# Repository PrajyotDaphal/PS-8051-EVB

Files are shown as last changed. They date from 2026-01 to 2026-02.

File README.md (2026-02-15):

# PS-8051-EVB  
**8051 Microcontroller Evaluation Board**

## 📌 Project Overview
PS-8051-EVB is a custom-designed **8051 microcontroller evaluation board** developed for embedded systems learning and prototyping. The board integrates a regulated 5V power supply, USB-to-UART communication using FT232RL, crystal oscillator, reset circuitry, and multiple 2.54 mm IDC connectors for external interfacing.

## ⚙️ Key Features
- 8051 microcontroller (40-pin DIP / ZIF socket compatible)
- Onboard 5V regulated power supply (L7805)
- USB-to-UART interface using FT232RL
- External crystal oscillator circuit
- Reset circuitry for reliable startup
- 2.54 mm IDC headers for I/O expansion
- Mounting holes for enclosure fitting

## 🛠 Tools Used
- KiCad EDA (Schematic & PCB Layout)

## 📐 Design Files
- Complete KiCad schematic and PCB layout
- Manufacturing-ready Gerber files
- Project images and documentation

## 🖼 Schematic
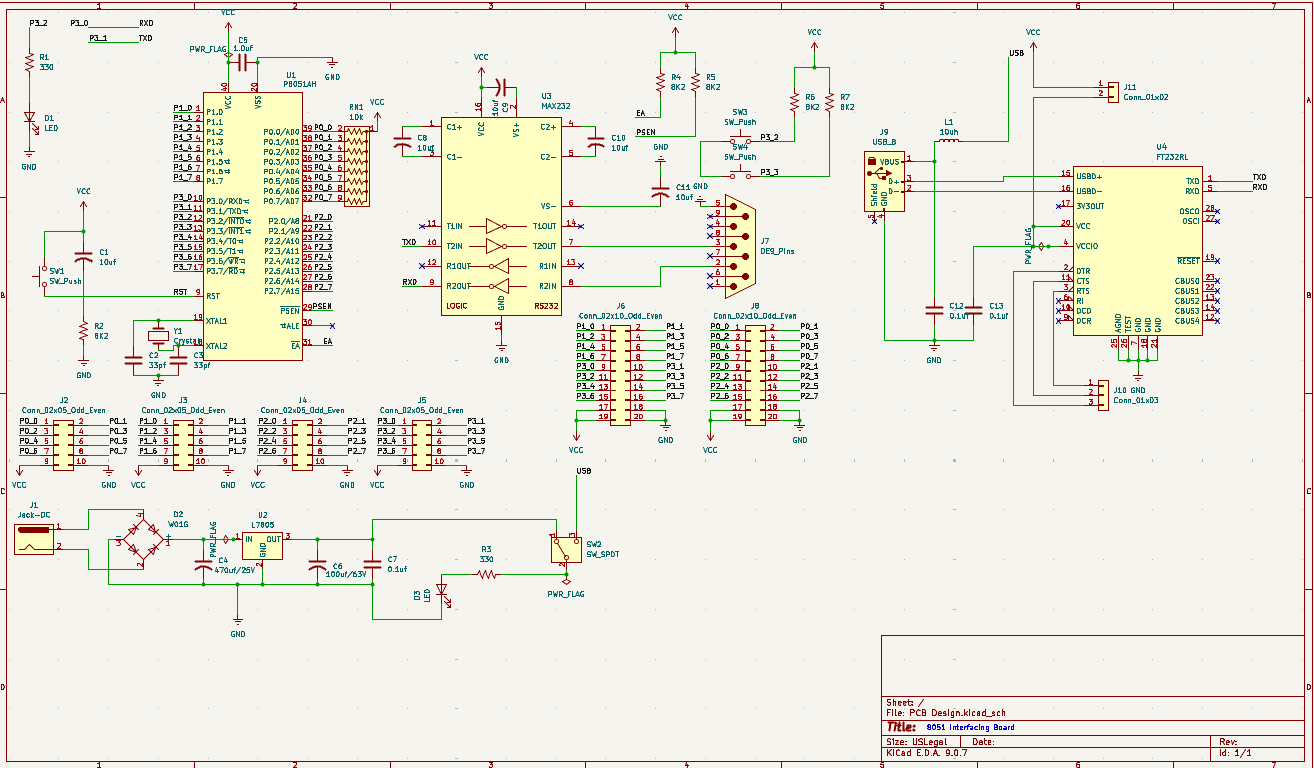
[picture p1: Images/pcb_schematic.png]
Schematic


## 🧩| Full Layout | Upper Copper | Lower Copper |
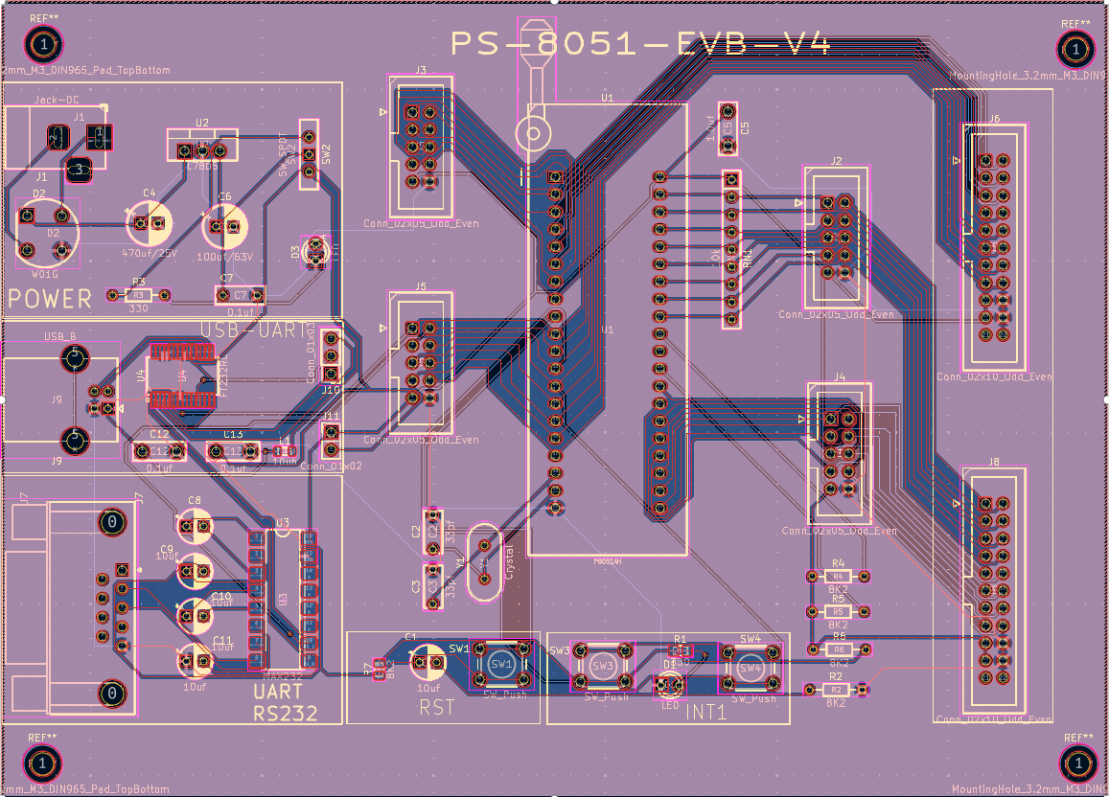
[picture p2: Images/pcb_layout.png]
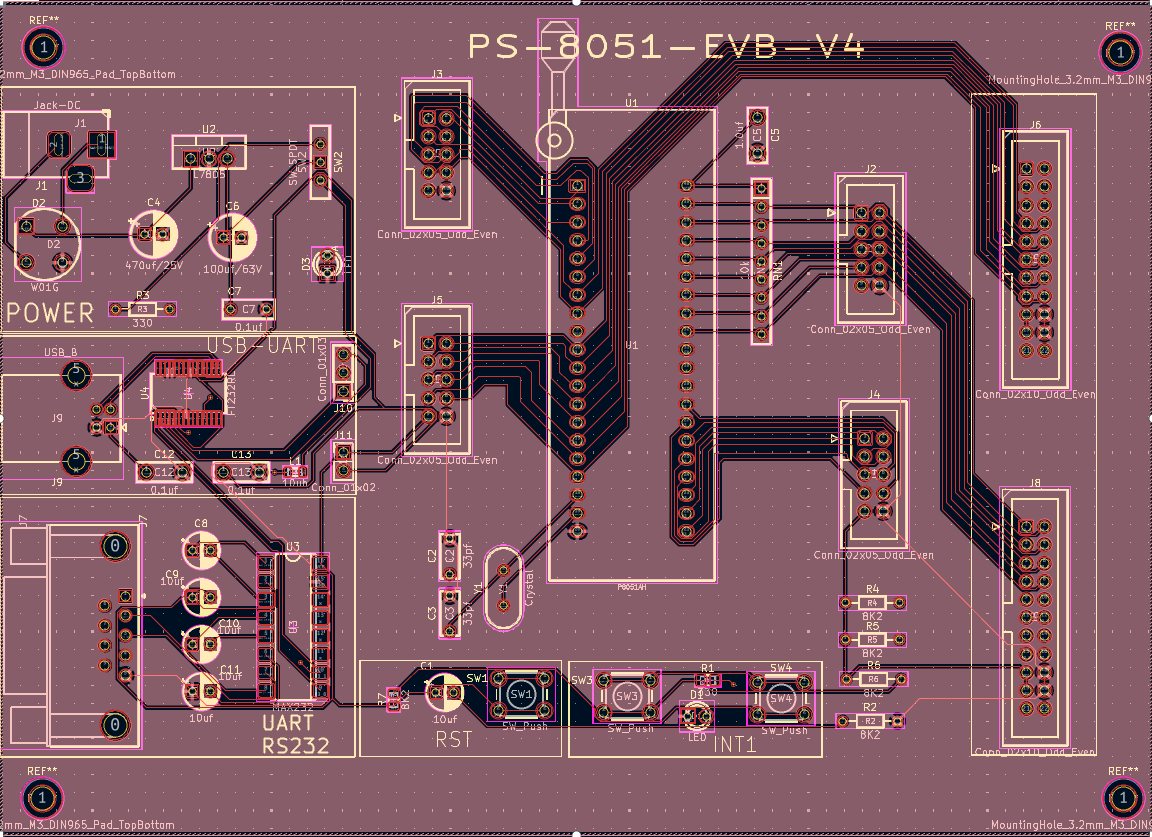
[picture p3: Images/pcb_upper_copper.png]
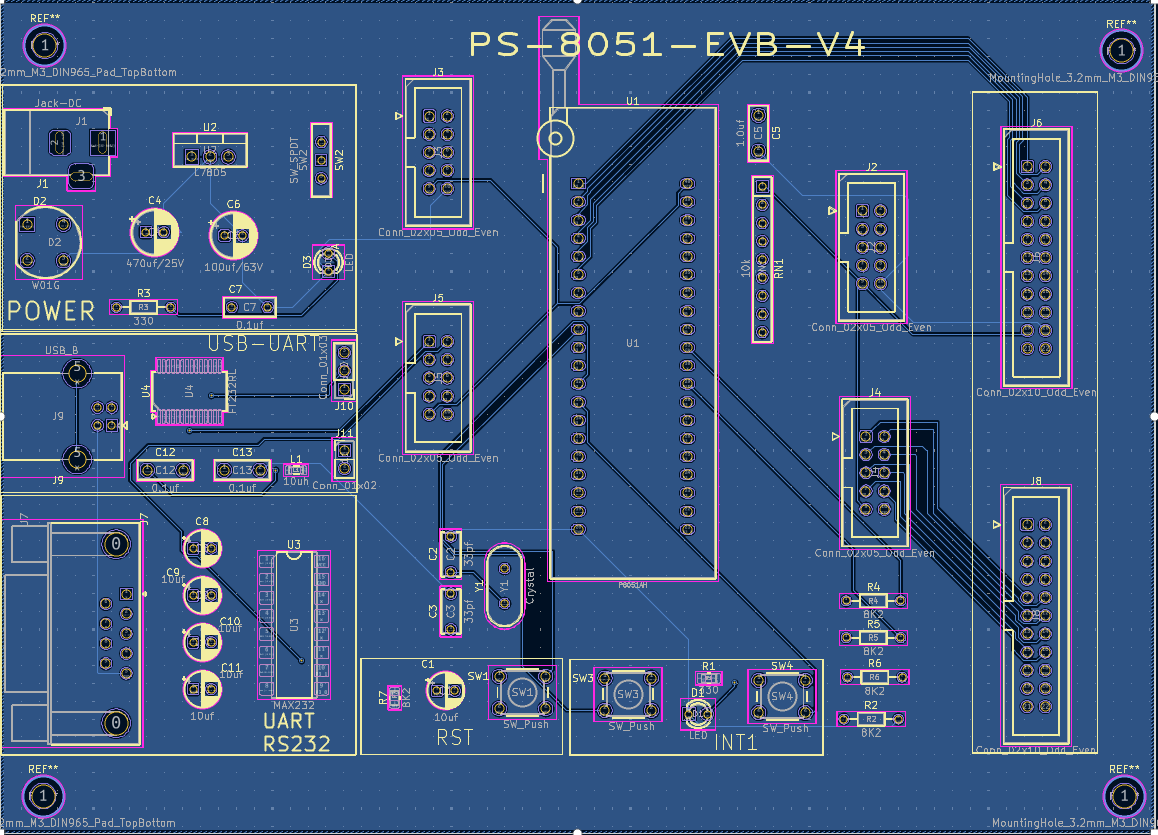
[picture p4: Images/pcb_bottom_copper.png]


## 🔷 PCB 3D View
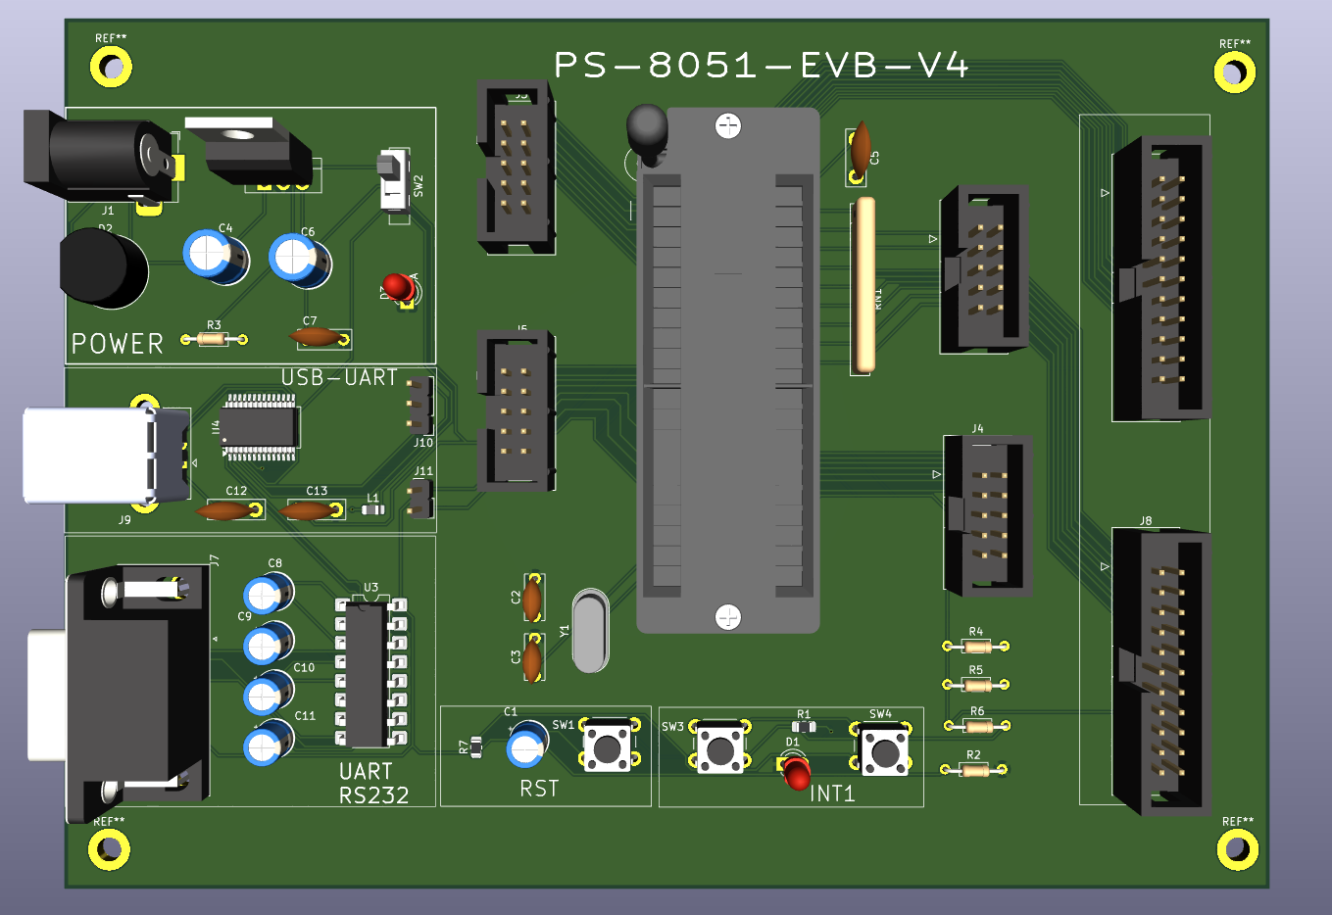
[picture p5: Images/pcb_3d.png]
PCB 3D


## 📂 Repository Structure
PS-8051-EVB/
├─ kicad/
├─ images/
├─ gerber/
├─ bom/
└─ README.md

## 🎯 Applications
- Embedded systems learning
- 8051 microcontroller experiments
- USB-based serial communication projects
- Academic and training use

## 👤 Author
**Prajyot Daphal**  
ENTC Engineering Student

---

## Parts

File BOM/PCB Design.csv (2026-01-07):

Id | Designator | Footprint | Quantity | Designation | Supplier and ref
1 | D3,D1 | LED_D3.0mm | 2 | LED
2 | C8,C9,C11,C10,C1 | CP_Radial_D5.0mm_P2.50mm | 5 | 10uf
3 | RN1 | R_Array_SIP9 | 1 | 10k
4 | U1 | DIP_Socket-40_W11.9mm_W12.7mm_W15.24mm_W17.78mm_W18.5mm_3M_240-1280-00-0602J | 1 | P8051AH
5 | R4,R5,R6,R2 | R_Axial_DIN0204_L3.6mm_D1.6mm_P7.62mm_Horizontal | 4 | 8K2
6 | J6,J8 | IDC-Header_2x10_P2.54mm_Vertical | 2 | Conn_02x10_Odd_Even
7 | SW2 | SW_Slide-03_Wuerth-WS-SLTV_10x2.5x6.4_P2.54mm | 1 | SW_SPDT
8 | J9 | USB_B_Lumberg_2411_02_Horizontal | 1 | USB_B
9 | J2,J4,J3,J5 | IDC-Header_2x05_P2.54mm_Vertical | 4 | Conn_02x05_Odd_Even
10 | Y1 | Crystal_HC49-4H_Vertical | 1 | Crystal
11 | J1 | BarrelJack_Horizontal | 1 | Jack-DC
12 | C12,C13 | C_Disc_D7.5mm_W2.5mm_P5.00mm | 2 | 0.1uf
13 | C3,C2 | C_Disc_D6.0mm_W2.5mm_P5.00mm | 2 | 33pf
14 | C4 | CP_Radial_D8.0mm_P5.00mm | 1 | 470uf/25V
15 | SW4,SW3,SW1 | SW_PUSH_6mm | 3 | SW_Push
16 | L1 | L_0805_2012Metric | 1 | 10uh
17 | J10 | PinHeader_1x03_P2.54mm_Vertical | 1 | Conn_01x03
18 | C6 | CP_Radial_D6.3mm_P2.50mm | 1 | 100uf/63V
19 | R1 | R_0805_2012Metric_Pad1.20x1.40mm_HandSolder | 1 | 330
20 | R3 | R_Axial_DIN0204_L3.6mm_D1.6mm_P7.62mm_Horizontal | 1 | 330
21 | C7 | C_Disc_D7.0mm_W2.5mm_P5.00mm | 1 | 0.1uf
22 | C5 | C_Disc_D7.5mm_W2.5mm_P5.00mm | 1 | 1.0uf
23 | R7 | R_0805_2012Metric | 1 | 8K2
24 | J7 | DSUB-9_Pins_Horizontal_P2.77x2.84mm_EdgePinOffset7.70mm_Housed_MountingHolesOffset9.12mm | 1 | DE9_Pins
25 | D2 | Diode_Bridge_Round_D9.8mm | 1 | W01G
26 | U2 | TO-220-3_Vertical | 1 | L7805
27 | U4 | SSOP-28_5.3x10.2mm_P0.65mm | 1 | FT232RL
28 | J11 | PinHeader_1x02_P2.54mm_Vertical | 1 | Conn_01x02
29 | U3 | SMDIP-16_W7.62mm | 1 | MAX232

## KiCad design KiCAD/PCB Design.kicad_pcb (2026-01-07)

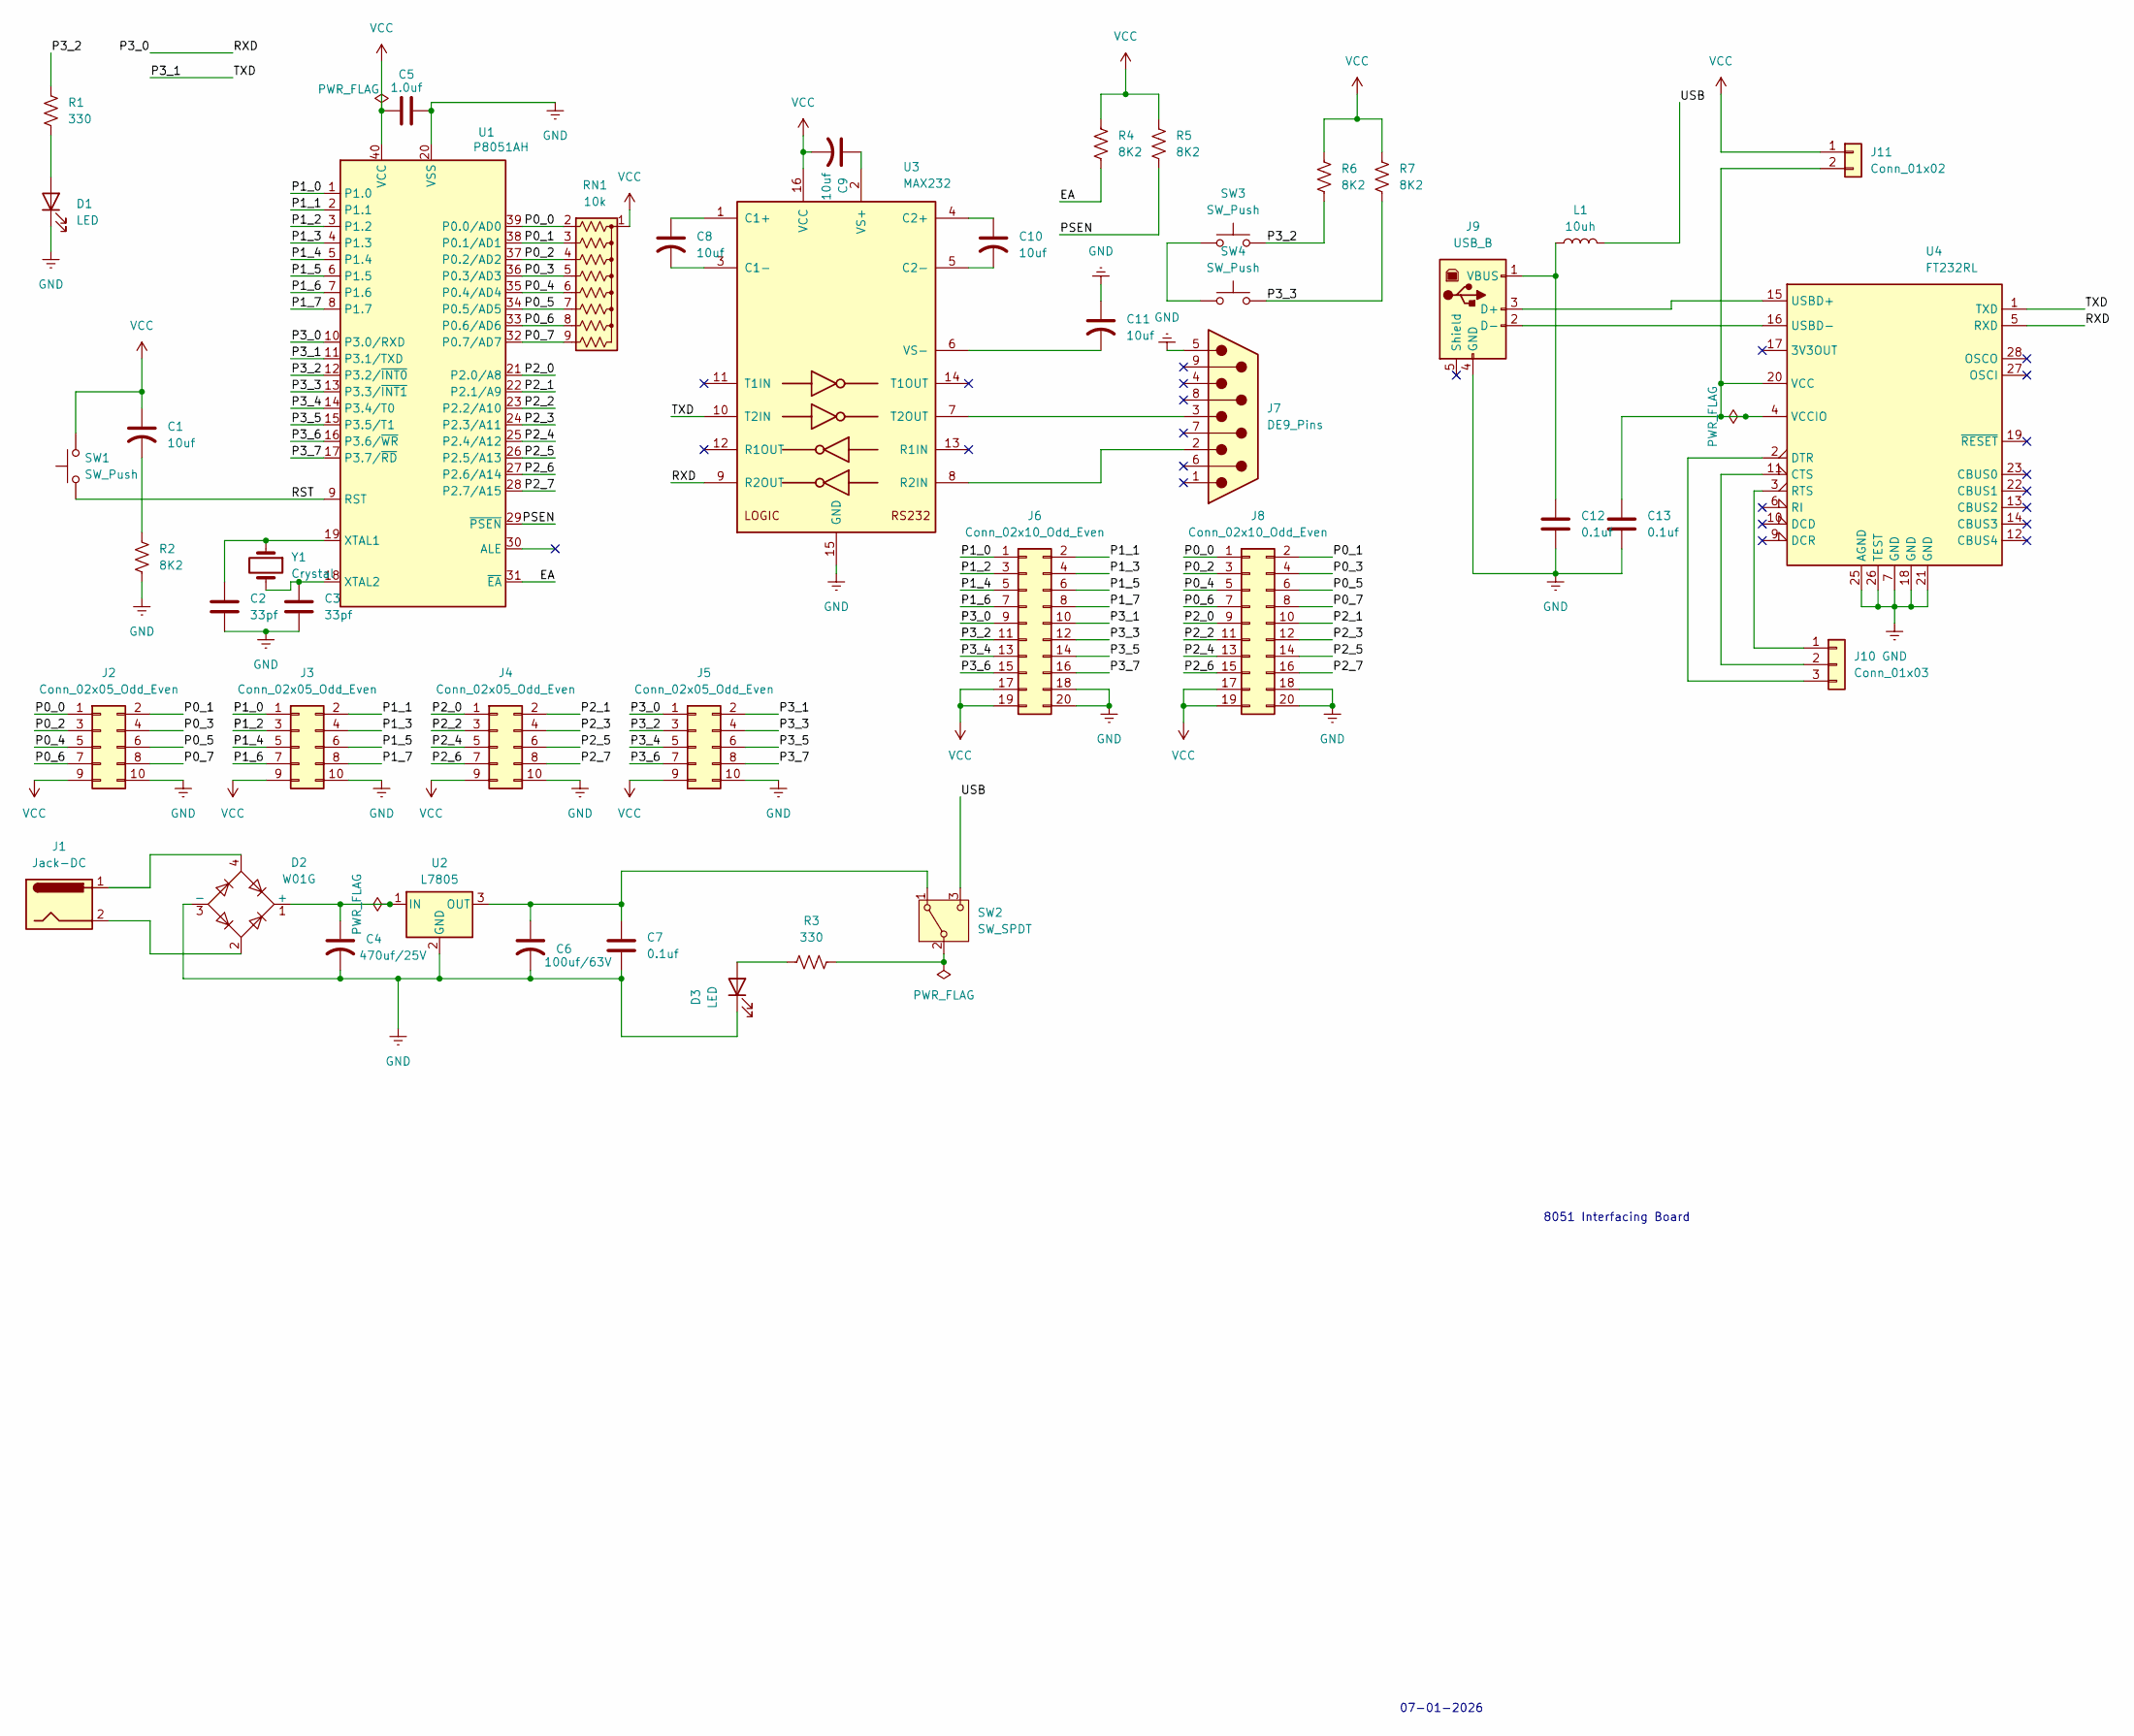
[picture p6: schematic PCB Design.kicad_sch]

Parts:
C1, C8, C9, C10, C11: 10uf; CP_Radial_D5.0mm_P2.50mm
C2, C3: 33pf; C_Disc_D6.0mm_W2.5mm_P5.00mm
C4: 470uf/25V; CP_Radial_D6.3mm_P2.50mm
C5: 1.0uf; C_Disc_D7.5mm_W2.5mm_P5.00mm
C6: 100uf/63V; CP_Radial_D6.3mm_P2.50mm
C7: 0.1uf; C_Disc_D7.0mm_W2.5mm_P5.00mm
C12, C13: 0.1uf; C_Disc_D7.5mm_W2.5mm_P5.00mm
D1, D3: LED; LED_D3.0mm
D2: W01G; Diode_Bridge_Round_D9.8mm
J1: Jack-DC; BarrelJack_Horizontal
J2, J3, J4, J5: Conn_02x05_Odd_Even; IDC-Header_2x05_P2.54mm_Vertical
J6, J8: Conn_02x10_Odd_Even; IDC-Header_2x11_P2.54mm_Vertical
J7: DE9_Pins; DSUB-9_Pins_Horizontal_P2.77x2.84mm_EdgePinOffset7.70mm_Hou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
J9: USB_B; USB_B_Lumberg_2411_02_Horizontal
J10: Conn_01x03; PinHeader_1x03_P2.54mm_Vertical
J11: Conn_01x02; PinHeader_1x02_P2.54mm_Vertical
L1: 10uh; L_0805_2012Metric
R1: 330; R_0805_2012Metric_Pad1.20x1.40mm_HandSolder
R2, R4, R5, R6: 8K2; R_Axial_DIN0204_L3.6mm_D1.6mm_P7.62mm_Horizontal
R3: 330; R_Axial_DIN0204_L3.6mm_D1.6mm_P7.62mm_Horizontal
R7: 8K2; R_0805_2012Metric
RN1: 10k; R_Array_SIP9
SW1, SW3, SW4: SW_Push; SW_PUSH_6mm
SW2: SW_SPDT; SW_Slide-03_Wuerth-WS-SLTV_10x2.5x6.4_P2.54mm
U1: P8051AH; DIP_Socket-40_W11.9mm_W12.7mm_W15.24mm_W17.78mm_W18.5mm_3M_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
U2: L7805; TO-220-3_Vertical
U3: MAX232; SMDIP-16_W7.62mm
U4: FT232RL; SSOP-28_5.3x10.2mm_P0.65mm
Y1: Crystal; Crystal_HC49-4H_Vertical

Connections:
/EA: R4.2, U1.31 (~EA)
/P0_0: J2.1, J8.1, RN1.2 (R1), U1.39 (P0.0/AD0)
/P0_1: J2.2, J8.2, RN1.3 (R2), U1.38 (P0.1/AD1)
/P0_2: J2.3, J8.3, RN1.4 (R3), U1.37 (P0.2/AD2)
/P0_3: J2.4, J8.4, RN1.5 (R4), U1.36 (P0.3/AD3)
/P0_4: J2.5, J8.5, RN1.6 (R5), U1.35 (P0.4/AD4)
/P0_5: J2.6, J8.6, RN1.7 (R6), U1.34 (P0.5/AD5)
/P0_6: J2.7, J8.7, RN1.8 (R7), U1.33 (P0.6/AD6)
/P0_7: J2.8, J8.8, RN1.9 (R8), U1.32 (P0.7/AD7)
/P1_0: J3.1, J6.1, U1.1 (P1.0)
/P1_1: J3.2, J6.2, U1.2 (P1.1)
/P1_2: J3.3, J6.3, U1.3 (P1.2)
/P1_3: J3.4, J6.4, U1.4 (P1.3)
/P1_4: J3.5, J6.5, U1.5 (P1.4)
/P1_5: J3.6, J6.6, U1.6 (P1.5)
/P1_6: J3.7, J6.7, U1.7 (P1.6)
/P1_7: J3.8, J6.8, U1.8 (P1.7)
/P2_0: J4.1, J8.9, U1.21 (P2.0/A8)
/P2_1: J4.2, J8.10, U1.22 (P2.1/A9)
/P2_2: J4.3, J8.11, U1.23 (P2.2/A10)
/P2_3: J4.4, J8.12, U1.24 (P2.3/A11)
/P2_4: J4.5, J8.13, U1.25 (P2.4/A12)
/P2_5: J4.6, J8.14, U1.26 (P2.5/A13)
/P2_6: J4.7, J8.15, U1.27 (P2.6/A14)
/P2_7: J4.8, J8.16, U1.28 (P2.7/A15)
/P3_0: J5.1, J6.9, U1.10 (P3.0/RXD), U3.9 (R2OUT), U4.5 (RXD)
/P3_1: J5.2, J6.10, U1.11 (P3.1/TXD), U3.10 (T2IN), U4.1 (TXD)
/P3_2: J5.3, J6.11, R1.1, R6.2, SW3.2, U1.12 (P3.2/~INT0)
/P3_3: J5.4, J6.12, R7.2, SW4.2, U1.13 (P3.3/~INT1)
/P3_4: J5.5, J6.13, U1.14 (P3.4/T0)
/P3_5: J5.6, J6.14, U1.15 (P3.5/T1)
/P3_6: J5.7, J6.15, U1.16 (P3.6/~WR)
/P3_7: J5.8, J6.16, U1.17 (P3.7/~RD)
/PSEN: R5.2, U1.29 (~PSEN)
/RST: SW1.1, U1.9 (RST)
/USB: L1.2, SW2.3 (C)
GND: C2.2, C3.2, C4.2, C5.2, C6.2, C7.2, C11.1, C12.2, C13.2, D1.1 (K), D2.3 (-), D3.1 (K), J2.10, J3.10, J4.10, J5.10, J6.18, J6.20, J7.5, J8.18, J8.20, J9.4 (GND), R2.2, U1.20 (VSS), U2.2 (GND), U3.15 (GND), U4.7 (GND), U4.18 (GND), U4.21 (GND), U4.25 (AGND), U4.26 (TEST)
unnamed: C1.2, R2.1
unnamed: D1.2 (A), R1.2
unnamed: C4.1, D2.1 (+), U2.1 (IN)
unnamed: D2.2, J1.2
unnamed: D2.4, J1.1
unnamed: D3.2 (A), R3.2
unnamed: J9.3 (D+), U4.15 (USBD+)
unnamed: J9.2 (D-), U4.16 (USBD-)
unnamed: C12.1, J9.1 (VBUS), L1.1
unnamed: J10.1, U4.3 (RTS)
unnamed: J10.2, U4.11 (CTS)
unnamed: J10.3, U4.2 (DTR)
unnamed: C13.1, J11.2, U4.4 (VCCIO), U4.20 (VCC)
unnamed: C6.1, C7.1, SW2.1 (A), U2.3 (OUT)
unnamed: R3.1, SW2.2 (B)
unnamed: SW3.1, SW4.1
unnamed: C2.1, U1.19 (XTAL1), Y1.1
unnamed: C3.1, U1.18 (XTAL2), Y1.2
unnamed: C8.1, U3.1 (C1+)
unnamed: C8.2, U3.3 (C1-)
unnamed: C10.1, U3.4 (C2+)
unnamed: C10.2, U3.5 (C2-)
unnamed: J7.2, U3.8 (R2IN)
unnamed: J7.3, U3.7 (T2OUT)
unnamed: C9.1, U3.2 (VS+)
unnamed: C11.2, U3.6 (VS-)
VCC: C1.1, C5.1, C9.2, J2.9, J3.9, J4.9, J5.9, J6.17, J6.19, J8.17, J8.19, J11.1, R4.1, R5.1, R6.1, R7.1, RN1.1 (common), SW1.2, U1.40 (VCC), U3.16 (VCC)

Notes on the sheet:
8051 Interfacing Board
07-01-2026

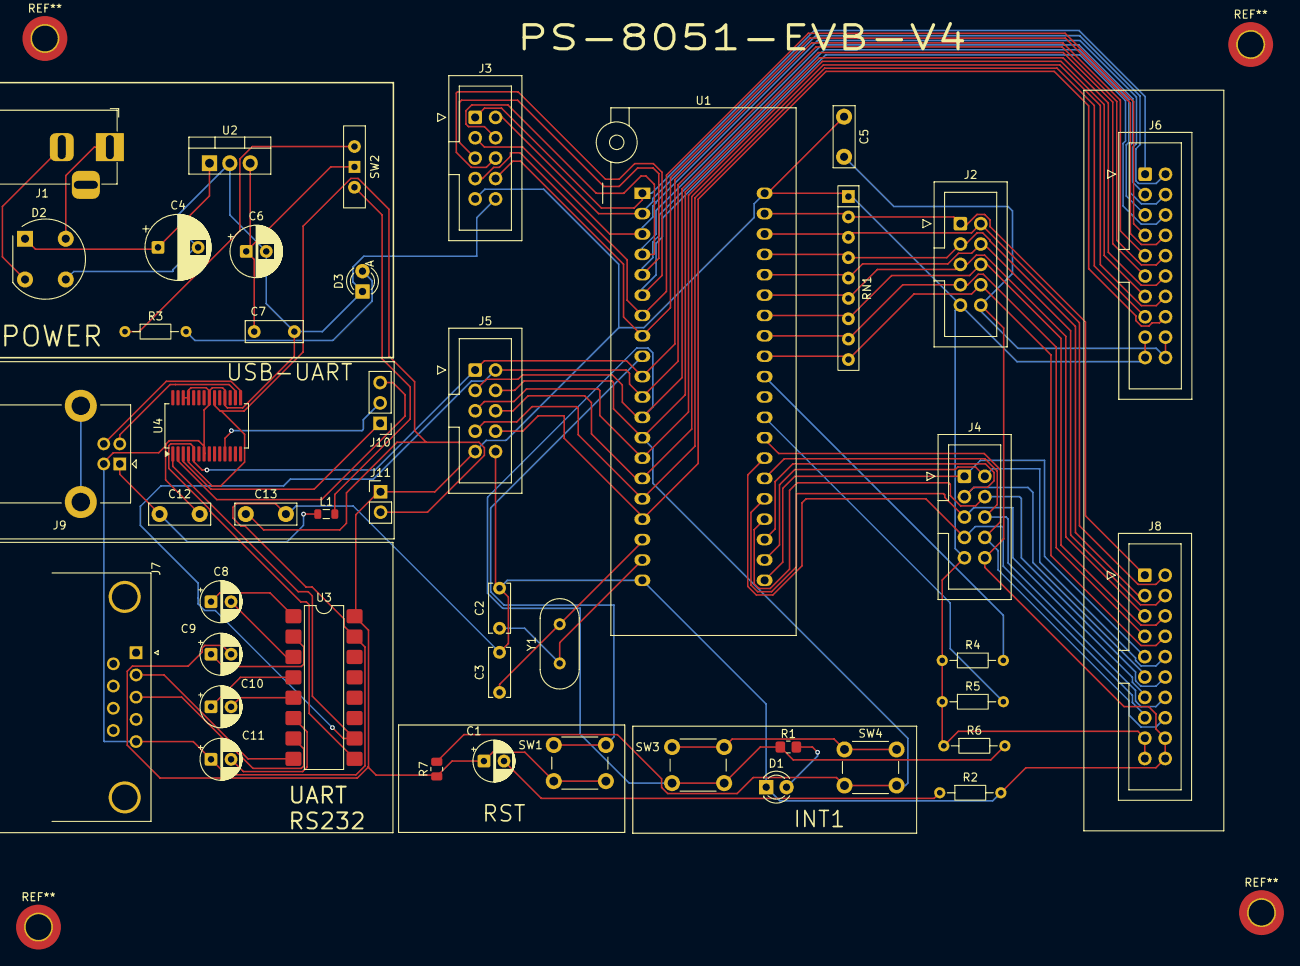
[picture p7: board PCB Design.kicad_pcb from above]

Board: 2 copper layers, 45 parts (0 on the bottom side), 64 nets.

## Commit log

2026-01-07 Create KiCAD
2026-01-07 Rename Screenshot 2026-01-07 213325.png to schematic.png
2026-01-07 Rename Screenshot 2026-01-07 212316.png to pcb_3d.png
2026-01-07 Rename Screenshot 2026-01-07 212248.png to pcb_layout.png
2026-02-15 Revise PCB Layout section with image table
    Updated PCB Layout section to include images in a table format.
